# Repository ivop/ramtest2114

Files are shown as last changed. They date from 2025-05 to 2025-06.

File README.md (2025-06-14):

# 2114 RAM Tester

The hardware is almost identical to [this](https://github.com/gpimblott/SRAM2114_Tester) project,
but the firmware is completely different and catches a lot of errors that would otherwise go
undetected.

### Hardware

Here's how to connect the 2114 to the Arduino Nano:

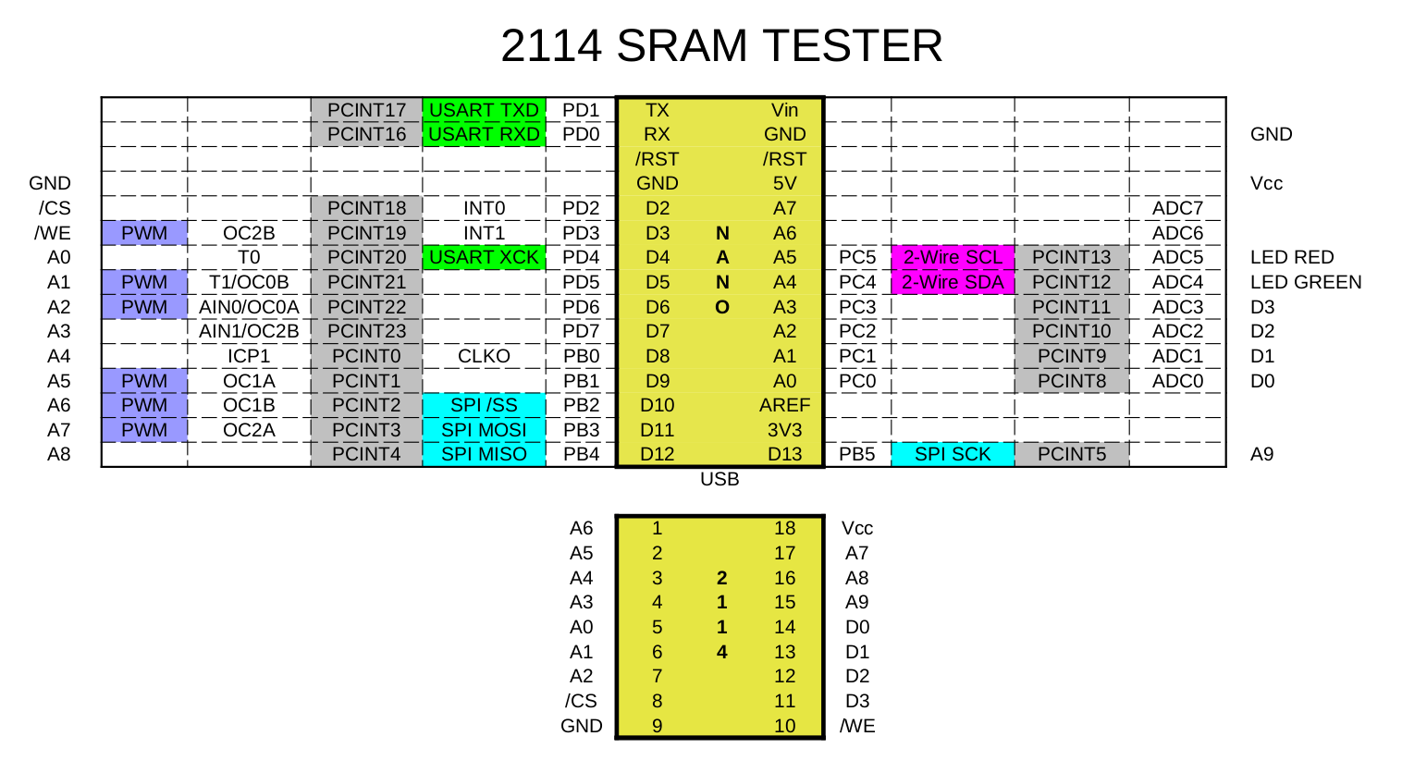
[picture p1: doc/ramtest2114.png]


Click the image for a larger version, or view the [pdf version](doc/ramtest2114.pdf).
Connect the LEDs through a 390 ohm resistor to ground.
It's important to orient the LED [the right way](https://www.switchelectronics.co.uk/blogs/news/led-polarity-basic-guide).
The plus side goes to the Nano, the negative side to the resistor to ground.
To ease testing multiple 2114s it's advised to use a ZIF socket.

### Gerbers

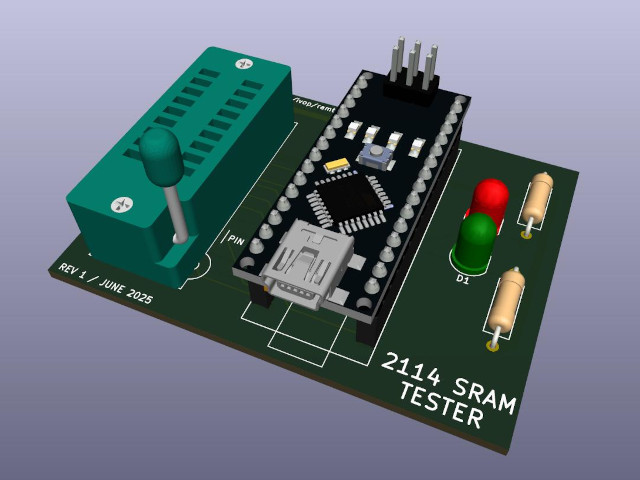
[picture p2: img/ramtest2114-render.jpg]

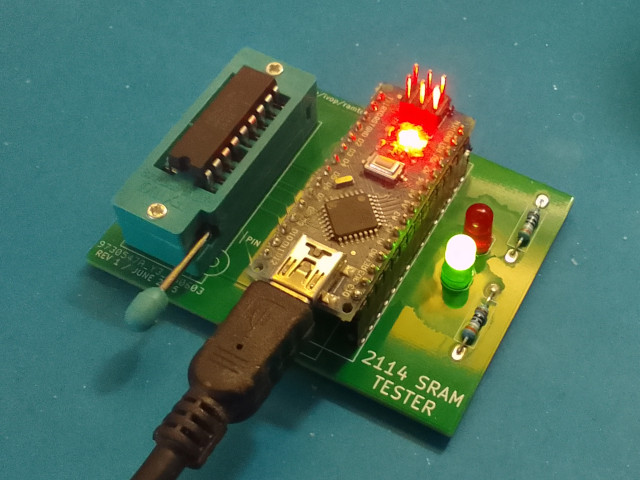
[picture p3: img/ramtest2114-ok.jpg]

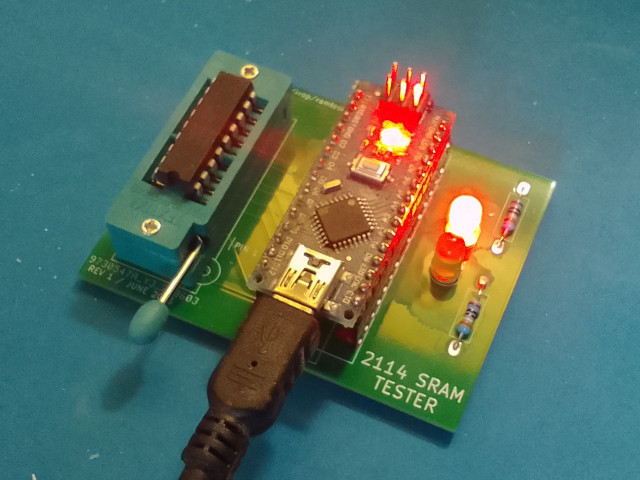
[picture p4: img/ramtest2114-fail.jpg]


In the [gerbers](kicad/gerbers) directory you'll find Gerber files for a complete PCB.
They have been tested to be working correctly.

### Flashing the firmware

Download [main.hex](https://github.com/ivop/ramtest2114/raw/refs/heads/master/main.hex) and use ```avrdude``` to flash it to the Arduino Nano.

```
avrdude -V -c arduino -b 57600 -P /dev/ttyUSB0 -p atmega328p -vv -U flash:w:main.hex
````

Replace ```/dev/ttyUSB0``` if your system is configured to assign a different serial device to your Nano.

### Usage

Insert a 2114 chip into the 18 pin socket and apply power to the Nano.
After booting it'll start testing immediately.
During the test, the red and green LEDs will blink.
When it's finished, either the green LED or the red LED stays on, indicating a success or a failure respectively.
Pressing the reset button on the Nano will rerun the test.
Be sure to disconnect the power when swapping the chip for another one to test.
Having the Vcc pin make contact without the ground pin being connected could damage the chip.

If you connect the Nano to the computer while testing, you can open a serial connection.
During the test, it'll print some diagnostic information, and a message when it's finished or encountered an error.

```
2114 SRAM MARCH MSS TESTER
^(w0)
^(r0,r0,w1,w1)
^(r1,r1,w0,w0)
...
...
v(r0,r0,w1,w1)
v(r1,r1,w0,w0)
v(r0)
RAM TESTED OK!
```

### Building the firmware from source

Install ```avr-gcc```, ```avr-libc```, and ```avrdude```.
Clone this repository and type ```make```.
Type ```make flash``` to automatically flash it to the connected Arduino Nano at ```/dev/ttyUSB0```.

### Algorithm

The tester uses the MARCH MSS algorithm.
It tests all combinations of the up/down (🡙) rules, and uses a set of three different background data value pairs to cover all errors it's able to detect.

Write errors:

* (W) SAF - Stuck At Fault
* (W) TF - Transition Fault
* (W) WDF - Write Destructive Fault
* (W) CFin - Inversion Coupling Fault
* (W) CFid - Idempotent Coupling Fault
* (W) CFst - Static Coupling Fault
* (W) CFds - Disturb Cell Coupling Fault
* (W) CFtr - Transition Coupling Fault
* (W) CFwd - Write Destructive Coupling

Read errors:

* (R) IRF - Incorrect Read Fault
* (R) RDF - Read Destructive Fault
* (R) DRDF - Deceptive Read Destructive Fault
* (R) SOF - Stuck Open Fault
* (R) ADF - Address Decoder Fault
* (R) CFds - Disturb Cell Coupling Fault
* (R) CFir - Incorrect Read Coupling Fault
* (R) CFrd - Read Destructive Coupling
* (R) CFir - Incorrect Read Coupling Fault

### References

* G. Harutunyan, V. A. Vardanian, and Y. Zorian, “Minimal march tests for unlinked static faults in random access memories,”
in 23rd IEEE VLSI Test Symposium (VTS’05), 2005, pp. 53–59, doi: 10.1109/VTS.2005.56.
[sci-hub link](https://sci-hub.se/10.1109/VTS.2005.56)
* [Understanding Memory Fault Models](https://www.embedded.com/understanding-memory-fault-models/)
( [archived version](https://web.archive.org/web/20240420233156/https://www.embedded.com/understanding-memory-fault-models/) )

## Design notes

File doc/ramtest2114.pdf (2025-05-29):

# 2114 SRAM TESTER

PCINT17 | USART TXD | PD1 | TX | Vin
PCINT16 | USART RXD | PD0 | RX | GND | GND
/RST | /RST
GND | GND | 5V | Vcc
/CS | PCINT18 | INT0 | PD2 | D2 | A7 | ADC7
/WE | PWM | OC2B | PCINT19 | INT1 | PD3 | D3 | N | A6 | ADC6
A0 | T0 | PCINT20 | USART XCK | PD4 | D4 | A | A5 | PC5 | 2-Wire SCL | PCINT13 | ADC5 | LED RED
A1 | PWM | T1/OC0B | PCINT21 | PD5 | D5 | N | A4 | PC4 | 2-Wire SDA | PCINT12 | ADC4 | LED GREEN
A2 | PWM | AIN0/OC0A | PCINT22 | PD6 | D6 | O | A3 | PC3 | PCINT11 | ADC3 | D3
A3 | AIN1/OC2B | PCINT23 | PD7 | D7 | A2 | PC2 | PCINT10 | ADC2 | D2
A4 | ICP1 | PCINT0 | CLKO | PB0 | D8 | A1 | PC1 | PCINT9 | ADC1 | D1
A5 | PWM | OC1A | PCINT1 | PB1 | D9 | A0 | PC0 | PCINT8 | ADC0 | D0
A6 | PWM | OC1B | PCINT2 | SPI /SS | PB2 | D10 | AREF
A7 | PWM | OC2A | PCINT3 | SPI MOSI | PB3 | D11 | 3V3
A8 | PCINT4 | SPI MISO | PB4 | D12 | D13 | PB5 | SPI SCK | PCINT5 | A9

USB

A6 | 1 | | 18 | Vcc
A5 | 2 | | 17 | A7
A4 | 3 | 2 | 16 | A8
A3 | 4 | 1 | 15 | A9
A0 | 5 | 1 | 14 | D0
A1 | 6 | 4 | 13 | D1
A2 | 7 | | 12 | D2
/CS | 8 | | 11 | D3
GND | 9 | | 10 | /WE

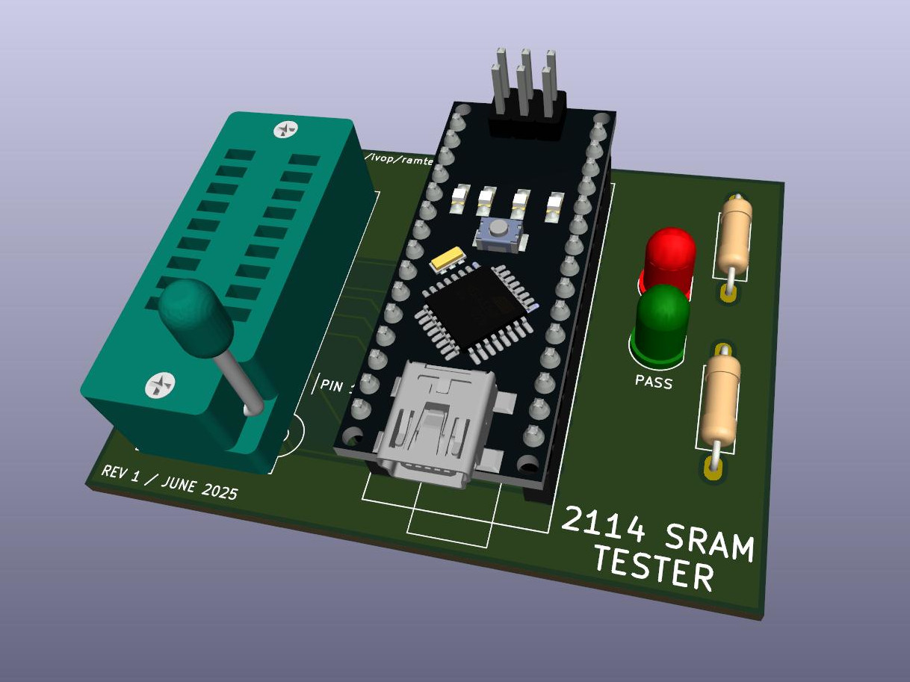
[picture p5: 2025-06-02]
kicad/ramtest2114.jpg

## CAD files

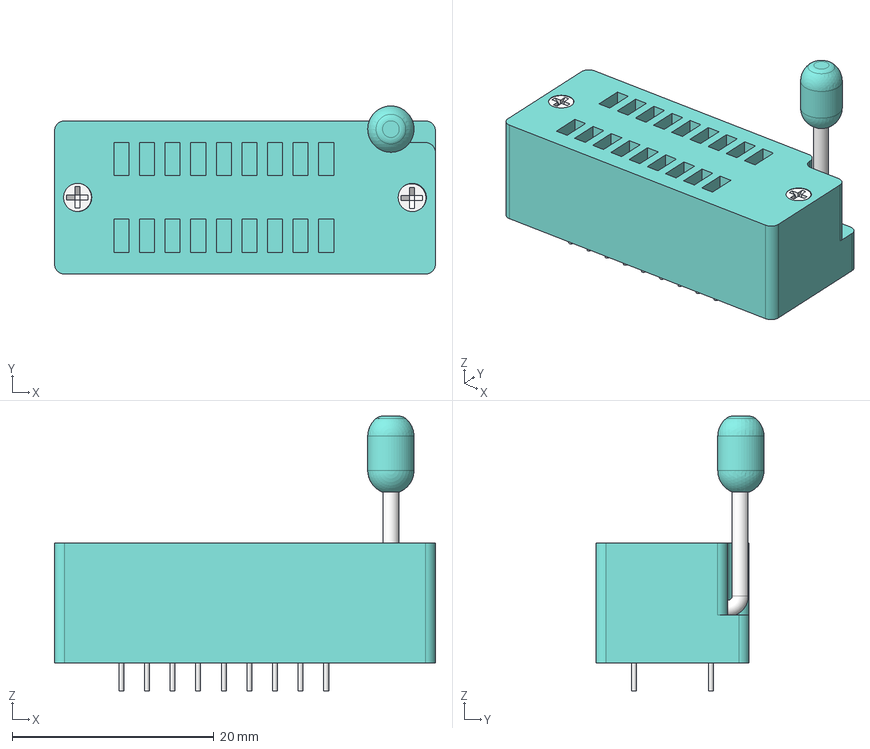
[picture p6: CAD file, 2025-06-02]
kicad/3dmodels/zif18.step
37.8 x 16.7 x 27.3 mm
04 Zif Socket Handle x 2
06 Zif Socket Screw x 2

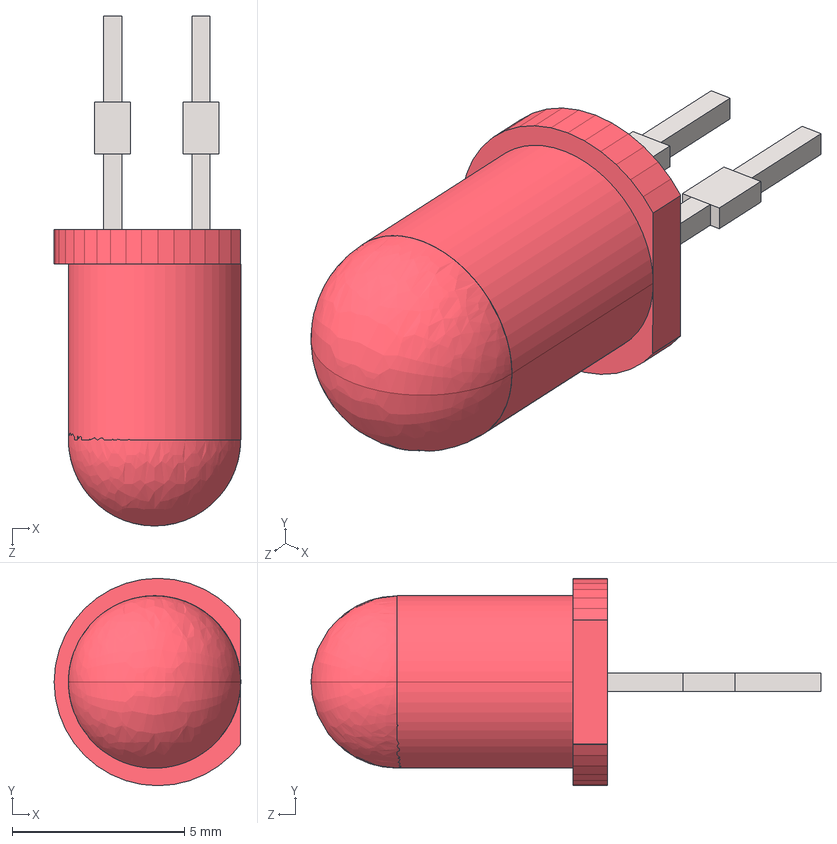
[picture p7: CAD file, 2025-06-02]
kicad/3dmodels/LED-Red-5mm.step
5.42 x 6.02 x 14.8 mm
ALSRobot-LED Red 5mm_SW3dPS-LEDd5R_Extruded3
ALSRobot-LED Red 5mm_SW3dPS-LEDd5R_Extruded x 2
ALSRobot-LED Red 5mm_SW3dPS-LEDd5R_Cylinder
ALSRobot-LED Red 5mm_SW3dPS-LEDd5R_Extruded4
ALSRobot-LED Red 5mm_SW3dPS-LEDd5R_Sphere
ALSRobot-LED Red 5mm_SW3dPS-LEDd5R_Extruded2 x 2
ALSRobot-LED Red 5mm_SW3dPS-LEDd5R_Extruded1

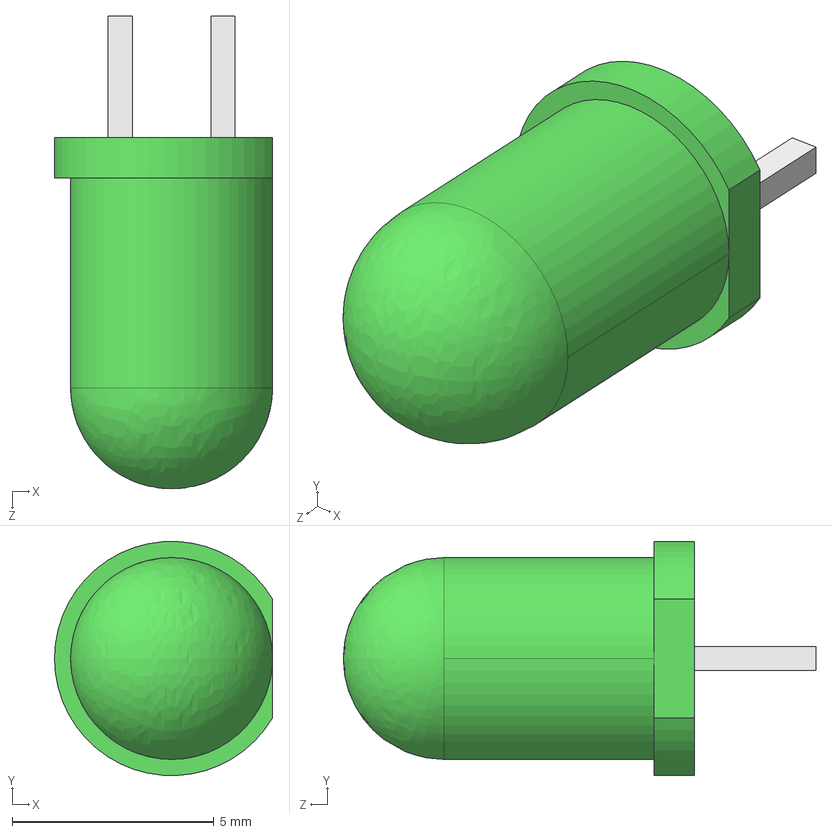
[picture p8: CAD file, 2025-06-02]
kicad/3dmodels/LED-Green-5mm.step
5.40 x 5.79 x 11.7 mm

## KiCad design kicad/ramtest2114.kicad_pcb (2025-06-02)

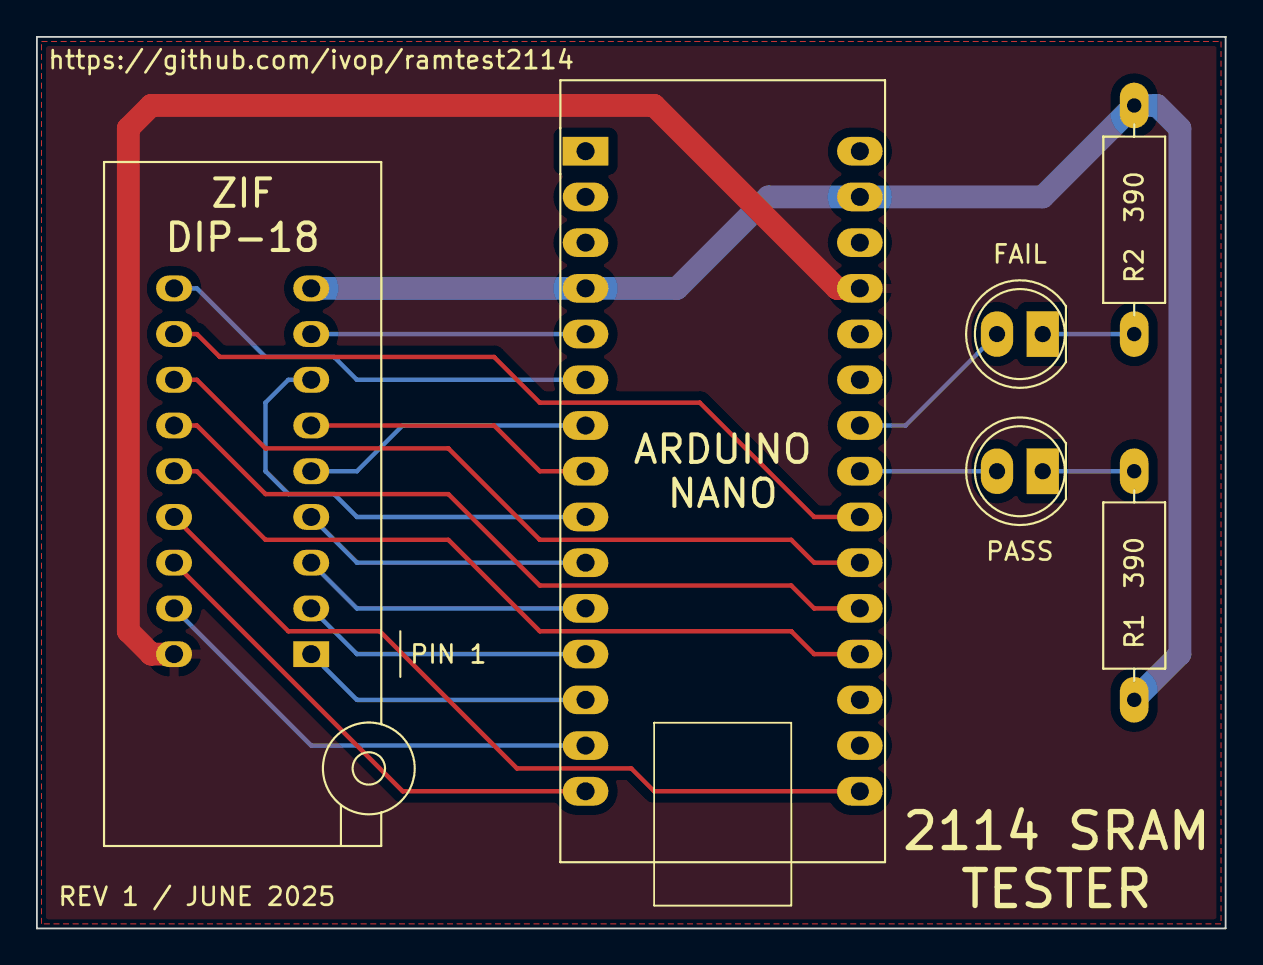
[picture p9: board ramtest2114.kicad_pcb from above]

Board: 2 copper layers, 66.0 x 49.5 mm, 6 parts (0 on the bottom side), 22 nets.

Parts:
D1: PASS; LED_D5.0mm
D2: FAIL; LED_D5.0mm
R1, R2: 390; R_Axial_DIN0309_L9.0mm_D3.2mm_P12.70mm_Horizontal
U1: Arduino_Nano; Arduino Nano
U2: 2114; DIP_Socket-18_W4.3_W5.08_W7.62_W10.16_W10.9_3M_218-3341-00-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

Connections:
+5V: U1.27 (5V), U2.18 (Vcc)
/A0: U1.7 (PD4), U2.5 (A0)
/A1: U1.8 (PD5), U2.6 (A1)
/A2: U1.9 (PD6), U2.7 (A2)
/A3: U1.10 (PD7), U2.4 (A3)
/A4: U1.11 (PB0), U2.3 (A4)
/A5: U1.12 (PB1), U2.2 (A5)
/A6: U1.13 (PB2), U2.1 (A6)
/A7: U1.14 (PB3), U2.17 (A7)
/A8: U1.15 (PB4), U2.16 (A8)
/A9: U1.16 (PB5), U2.15 (A9)
/D0: U1.19 (PC0), U2.14 (D0)
/D1: U1.20 (PC1), U2.13 (D1)
/D2: U1.21 (PC2), U2.12 (D2)
/D3: U1.22 (PC3), U2.11 (D3)
/~CS: U1.5 (PD2), U2.8 (~CS)
/~WE: U1.6 (PD3), U2.10 (~WE)
GND: R1.2, R2.2, U1.4 (GND), U1.29 (GND), U2.9 (GND)
unnamed: D1.1 (K), R1.1
unnamed: D1.2 (A), U1.23 (PC4)
unnamed: D2.1 (K), R2.1
unnamed: D2.2 (A), U1.24 (PC5)

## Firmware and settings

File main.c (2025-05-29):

// ramtest2114 - 2114 RAM tester
//
// MARCH (M)SS Algorithm
//
// Copyright © 2025 by Ivo van Poorten
// BSD 2-Clause License
// See LICENSE file for details
//
// MARCH MSS = { 🡙(w0); 🡑(r0,r0,w1,w1); 🡑(r1,r1,w0,w0); 🡓(r0,r0,w1,w1);
//               🡓(r1,r1,w0,w0); 🡙(r0) }
//
// Arduino Nano V3 (ATmega328 16MHz, 32kB Flash, 1kB ROM, 2kB RAM)
// Hardware similar to:
// https://github.com/gpimblott/SRAM2114_Tester
//
// PD2 = /CS
// PD3 = /WE
//
// PD4-PD7 = A0-A3
// PB0-PB5 = A4-A9
//
// PC0-PC3 = D0-D3
//
// PC4 green LED
// PC5 red LED


#include <stdio.h>
#include <stdint.h>
#include <avr/io.h>
#include <util/delay.h>

enum pins {
    PIN_CS    = 0b00000100,
    PIN_WE    = 0b00001000,
    PINS_DB   = 0b00001111,
    PINS_A0A3 = 0b11110000,
    PINS_A4A9 = 0b00111111,
    PIN_LEDG  = 0b00010000,
    PIN_LEDR  = 0b00100000,
    PINS_LEDS = 0b00110000
};

enum shifts {
    SHIFT_A0A3 = 4,
    SHIFT_A4A9 = 0
};

// ----------------------------------------------------------------------------

static void hw_usart_init(unsigned int ubrr) {
    UBRR0H = ubrr>>8;
    UBRR0L = ubrr;
    UCSR0B = 0;                             // disable all
    UCSR0B = _BV(RXEN0)  | _BV(TXEN0);      // enable RX and TX
    UCSR0C = _BV(UCSZ01) | _BV(UCSZ00);     // 8N1
//    UCSR0A = _BV(U2X0);                     // Double Speed
}

static void hw_usart_tx_byte(uint8_t byte) {
    while(!(UCSR0A & _BV(UDRE0))) ;         // wait for port ready to write
    UDR0 = byte;
}

static uint8_t hw_usart_rx_byte(void) {
    while(!(UCSR0A & _BV(RXC0))) ;          // wait for byte received
    return UDR0;
}

static void hw_usart_tx_block(const void *const buf, uint16_t len) {
    const uint8_t *b = buf;
    while (len--)
        hw_usart_tx_byte(*b++);
}

static void hw_usart_rx_block(void *const buf, uint16_t len) {
    uint8_t *b = buf;
    while (len--)
        *b++ = hw_usart_rx_byte();
}

static void hw_usart_tx_string(char *s) {
    while(*s) hw_usart_tx_byte(*s++);
}

// ----------------------------------------------------------------------------

static void led_green_on(void)  { PORTC |=  PIN_LEDG; };
static void led_green_off(void) { PORTC &= ~PIN_LEDG; };
static void led_red_on(void)    { PORTC |=  PIN_LEDR; };
static void led_red_off(void)   { PORTC &= ~PIN_LEDR; };

static inline void enable_cs(void)  { PORTD &= ~PIN_CS; }
static inline void disable_cs(void) { PORTD |=  PIN_CS; }
static inline void enable_we(void)  { PORTD &= ~PIN_WE; }
static inline void disable_we(void) { PORTD |=  PIN_WE; }

static inline void set_databus_output(void) { DDRC |=  PINS_DB; }
static inline void set_databus_input(void)  { DDRC &= ~PINS_DB; }

static void put_address_bus(uint16_t a) {
    PORTD &= ~PINS_A0A3;
    PORTD |= (a & 0x0f) << SHIFT_A0A3;
    PORTB &= ~PINS_A4A9;
    PORTB |= (a >> 4) << SHIFT_A4A9;
}

static void put_databus(uint8_t v) {
    PORTC &= ~PINS_DB;
    PORTC |= v & 0x0f;
}

static uint8_t get_databus(void) {
    return PINC & PINS_DB;
}

static uint8_t ram_read(uint16_t a) {
    put_address_bus(a);

    enable_cs();
    _delay_us(1);
    uint8_t v = get_databus();
    disable_cs();

    return v;
}

static void ram_write(uint16_t a, uint8_t v) {
    put_address_bus(a);

    set_databus_output();
    put_databus(v);

    enable_cs();
    enable_we();
    _delay_us(1);
    disable_we();
    disable_cs();

    set_databus_input();
}

// ----------------------------------------------------------------------------

static void fail(uint16_t a, uint8_t v, uint8_t e, int w) {
    hw_usart_tx_string("FAIL!\r\n");
    char s[128];
    snprintf(s, 128, "a=%03x, v=%1x, expected=%1x, line=%d\r\n", a, v, e, w);
    hw_usart_tx_string(s);
    led_green_off();
    led_red_on();
    while(1) ;
}

// ----------------------------------------------------------------------------

int main(void) {
    uint8_t updown = 0;         // bit 0 🡙(w0), bit 1 🡙(r0)
    uint8_t zero = 0b0000;
    uint8_t one = 0b1111;
    int a;
    uint8_t v;
    uint8_t bg_zero[3] = { 0b0000, 0b0011, 0b0101 };
    uint8_t bg_one[3]  = { 0b1111, 0b1100, 0b1010 };
    uint8_t bgidx = 0;

    hw_usart_init(103);         // 9600 baud, debug console

    DDRD |= 0b11111100;         // PD2-PD7 output   (/CS, /WE, A0-A3)
    DDRB |= 0b00111111;         // PB0-PB5 output   (A4-A9)
    DDRC |= PINS_LEDS;          // PC4-PC5 LEDs

    hw_usart_tx_string("2114 SRAM MARCH MSS TESTER\r\n");

    while (1) {

        if (!(updown &1)) {
            led_green_on();
            led_red_on();
        } else {
            led_green_off();
            led_red_off();
        }

        zero = bg_zero[bgidx];
        one  = bg_one[bgidx];

        // 🡙(w0)

        if (!(updown & 1)) {
            hw_usart_tx_string("^(w0)\r\n");
            for (a=0; a<1024; a++) {
                ram_write(a, zero);
            }
        } else {
            hw_usart_tx_string("v(w0)\r\n");
            for (a=1023; a>=0; a--) {
                ram_write(a, zero);
            }
        }

        // 🡑(r0,r0,w1,w1)

        hw_usart_tx_string("^(r0,r0,w1,w1)\r\n");
        for (a=0; a<1024; a++) {
            v = ram_read(a);
            if (v != zero) fail(a,v,zero,__LINE__);
            v = ram_read(a);
            if (v != zero) fail(a,v,zero,__LINE__);
            ram_write(a, one);
            ram_write(a, one);
        }

        // 🡑(r1,r1,w0,w0)

        hw_usart_tx_string("^(r1,r1,w0,w0)\r\n");
        for (int a=0; a<1024; a++) {
            v = ram_read(a);
            if (v != one) fail(a,v,one,__LINE__);
            v = ram_read(a);
            if (v != one) fail(a,v,one,__LINE__);
            ram_write(a, zero);
            ram_write(a, zero);
        }

        // 🡓(r0,r0,w1,w1)

        hw_usart_tx_string("v(r0,r0,w1,w1)\r\n");
        for (a=1023; a>=0; a--) {
            v = ram_read(a);
            if (v != zero) fail(a,v,zero,__LINE__);
            v = ram_read(a);
            if (v != zero) fail(a,v,zero,__LINE__);
            ram_write(a, one);
            ram_write(a, one);
        }

        // 🡓(r1,r1,w0,w0)

        hw_usart_tx_string("v(r1,r1,w0,w0)\r\n");
        for (int a=1023; a>=0; a--) {
            v = ram_read(a);
            if (v != one) fail(a,v,one,__LINE__);
            v = ram_read(a);
            if (v != one) fail(a,v,one,__LINE__);
            ram_write(a, zero);
            ram_write(a, zero);
        }

        // 🡙(r0)

        if (!(updown & 2)) {
            hw_usart_tx_string("^(r0)\r\n");
            for (a=0; a<1024; a++) {
                v = ram_read(a);
                if (v != zero) fail(a,v,zero,__LINE__);
            }
        } else {
            hw_usart_tx_string("v(r0)\r\n");
            for (a=1023; a>=0; a--) {
                v = ram_read(a);
                if (v != zero) fail(a,v,zero,__LINE__);
            }
        }

        updown++;
        if (updown == 4) {
            updown = 0;
            bgidx++;
            if (bgidx == 3) {
                hw_usart_tx_string("RAM TESTED OK!\r\n");
                led_green_on();
                led_red_off();
                while(1);
            }
        }
    }
}

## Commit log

2025-05-29 Add ods, pdf, and png
    [ramtest2114.ods]
2025-06-02 Add revision 1 of PCB.
    [LED-Green-5mm.step, LED-Red-5mm.step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]
2025-06-14 Add images (KiCad render, plus an OK and a FAIL photo of real hardware)
